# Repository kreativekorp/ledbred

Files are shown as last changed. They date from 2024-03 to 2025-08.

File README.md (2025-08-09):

# ledbred
Led·Bred

## Bill of Materials

* 1x [Arduino Mega 2560 R3](https://store.arduino.cc/products/arduino-mega-2560-rev3) or compatible clone
* 1x [Screw Terminal Shield](https://www.adafruit.com/product/196)
* 1x [MicroSD Shield](https://www.adafruit.com/product/1141)
* 3x [32x8 NeoPixel RGB LED Matrix](https://www.adafruit.com/product/2294) (no longer stocked by Adafruit but clones can be found easily)
* 1x [Breadboard-Friendly NeoPixel RGB LED](https://www.adafruit.com/product/1312)
* 1x [Rotary Encoder with Pushbutton](https://www.adafruit.com/product/377)
* 1x [Monochrome 128x32 SPI OLED Display](https://www.adafruit.com/product/661)
* 1x [HB15CKW01-5F-FB Illuminated Pushbutton](https://www.digikey.com/en/products/detail/nkk-switches/HB15CKW01-5F-FB/1056630)
* 1x [TEPT4400 Photodiode](https://www.digikey.com/en/products/detail/vishay-semiconductor-opto-division/TEPT4400/1681191)
* 1x [Lamping Tool](https://www.digikey.com/en/products/detail/nkk-switches/AT111/1050064) (highly recommended)
* 1x [1MΩ Through-Hole Resistor](https://www.digikey.com/en/products/detail/stackpole-electronics-inc/CF14JT1M00/1741316)

## Construction Diagram

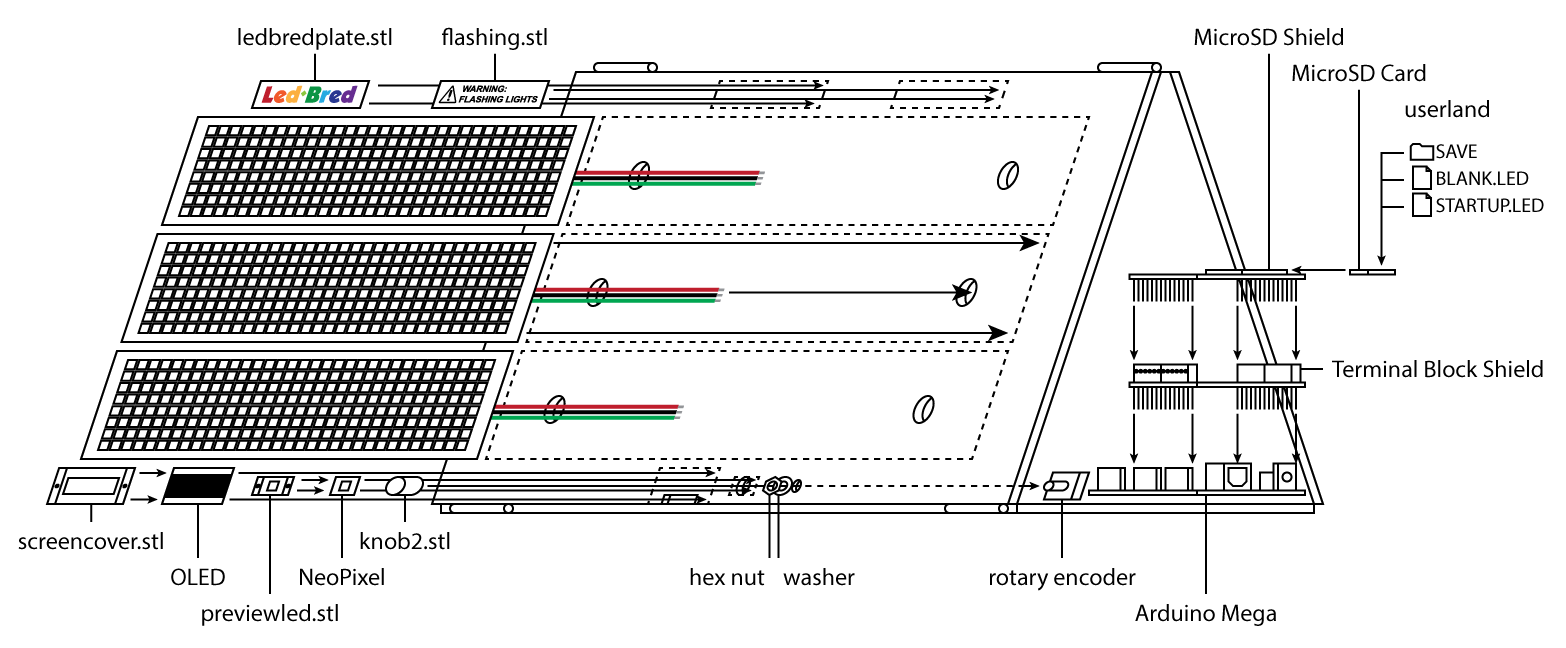
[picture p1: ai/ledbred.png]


## Constructing the pen

1. Use the lamping tool to replace the LED in the illuminated pushbutton with the TEPT4400 photodiode.
2. Blacken the side of the illuminated pushbutton's cap with a Sharpie. (This keeps out ambient light to improve detection.)
3. Install the illuminated pushbutton in the light pen top cap (`pencap1.stl`).
4. Feed the light pen cable through the light pen bottom cap (`pencap2.stl`).
5. Feed the light pen cable through the light pen barrel (`penbarrel.stl`).
6. Solder the wires of the light pen cable to the pins of the illuminated pushbutton.
7. Push the end caps into the barrel.

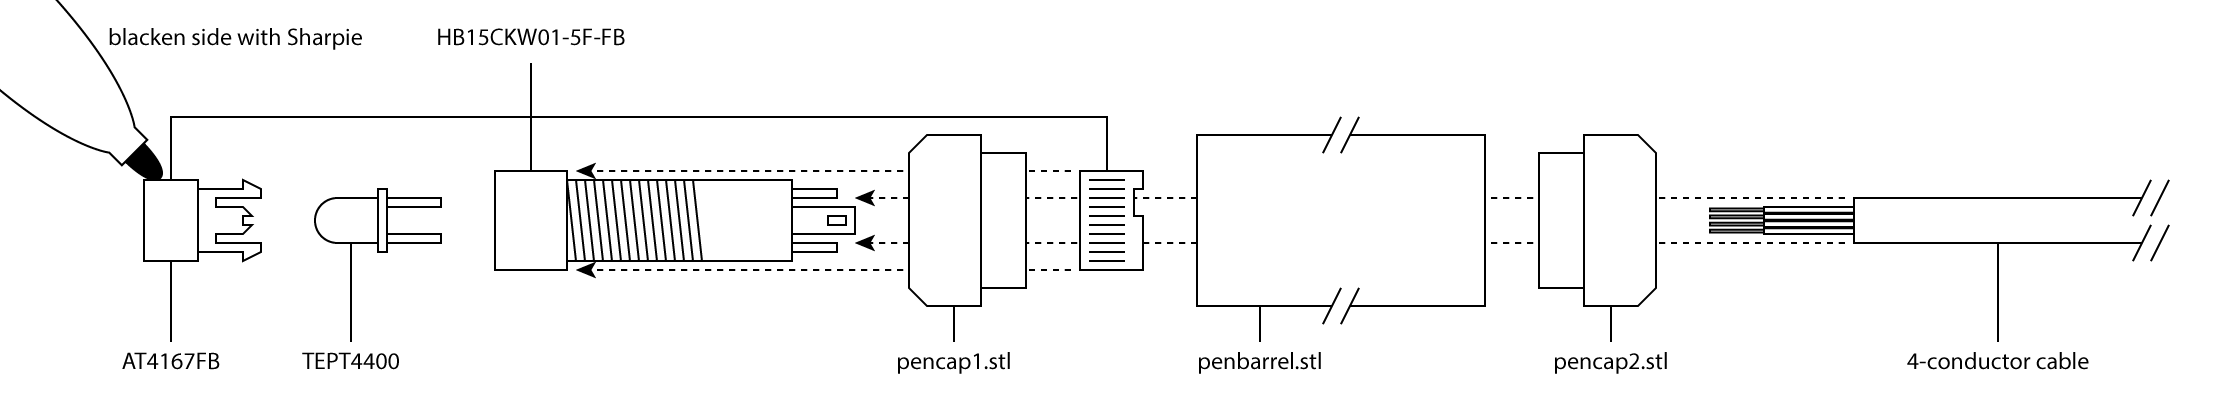
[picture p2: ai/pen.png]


## Wiring Diagram

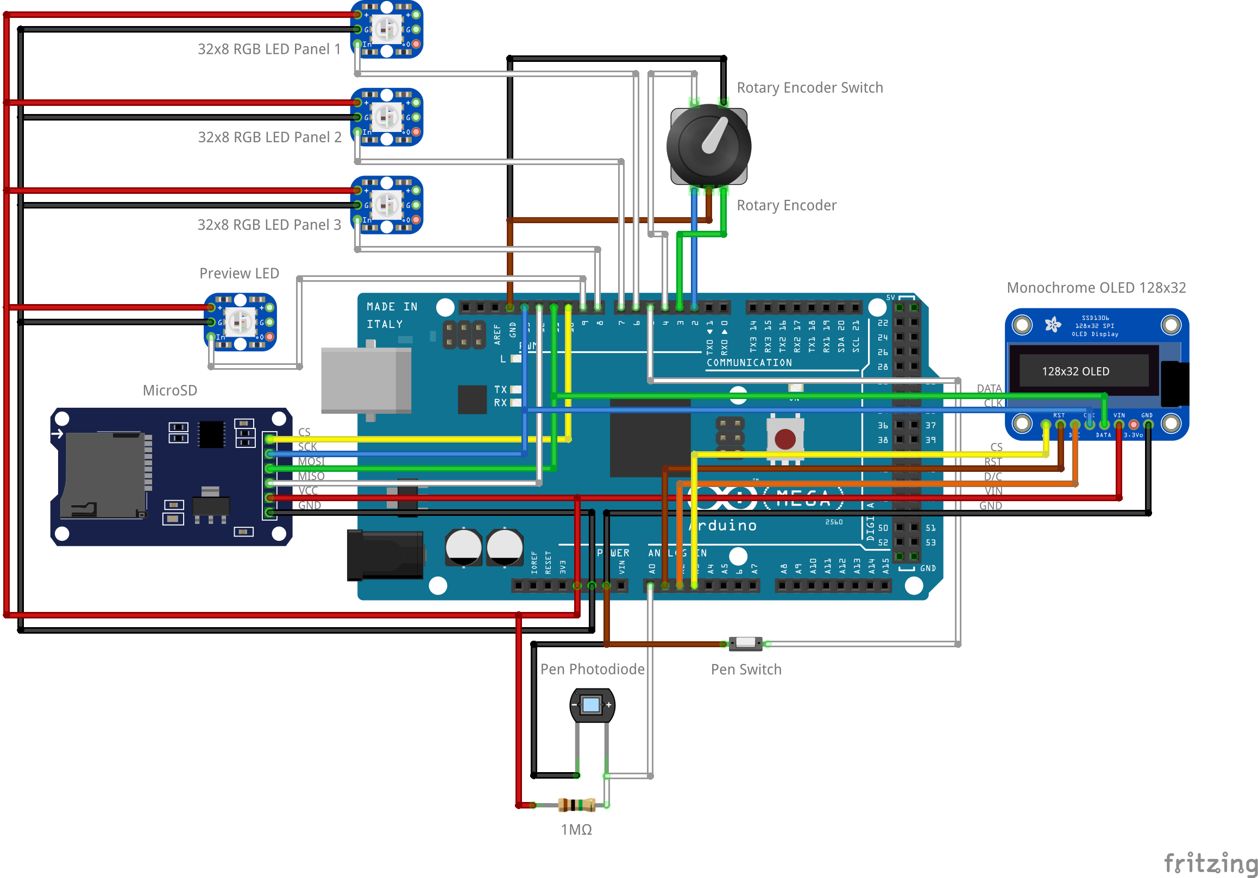
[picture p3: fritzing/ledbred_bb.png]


## Wiring Connections

* Rotary encoder left pin to Arduino D2
* Rotary encoder center pin to GND
* Rotary encoder right pin to Arduino D3
* Rotary encoder switch pin 1 to Arduino D4
* Rotary encoder switch pin 2 to GND
* Illuminated pushbutton switch pin 1 to Arduino D5
* Illuminated pushbutton switch pin 2 to GND
* Top RGB LED matrix DATA IN to Arduino D6
* Center RGB LED matrix DATA IN to Arduino D7
* Bottom RGB LED matrix DATA IN to Arduino D8
* Individual RGB LED DATA IN to Arduino D9
* OLED DATA/MOSI to Arduino D11
* OLED CLK/SCK to Arduino D13
* OLED CS to Arduino A3
* OLED D/C to Arduino A2
* OLED RST to Arduino A1
* Illuminated pushbutton LED anode to Arduino A0
* Illuminated pushbutton LED anode to 1MΩ resistor
* 1MΩ resistor to VCC
* Illuminated pushbutton LED cathode to GND

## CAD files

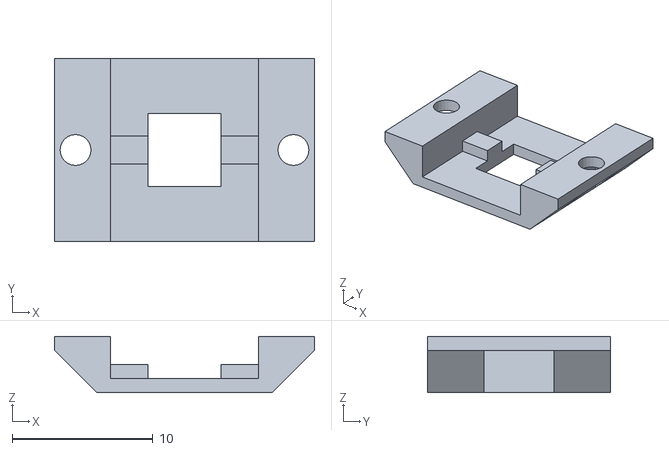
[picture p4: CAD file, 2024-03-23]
stl/previewled.stl
18.5 x 13.0 x 4.00

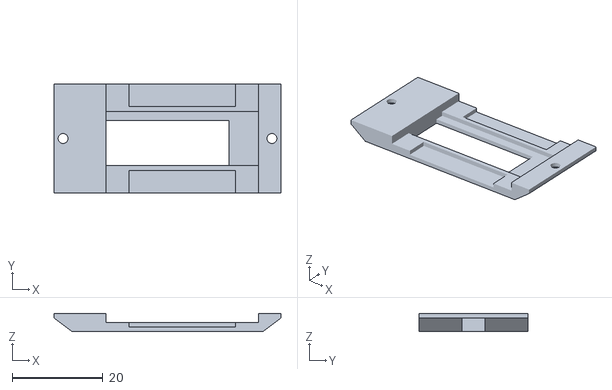
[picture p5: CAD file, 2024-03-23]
stl/screencover.stl
50.0 x 24.0 x 4.00

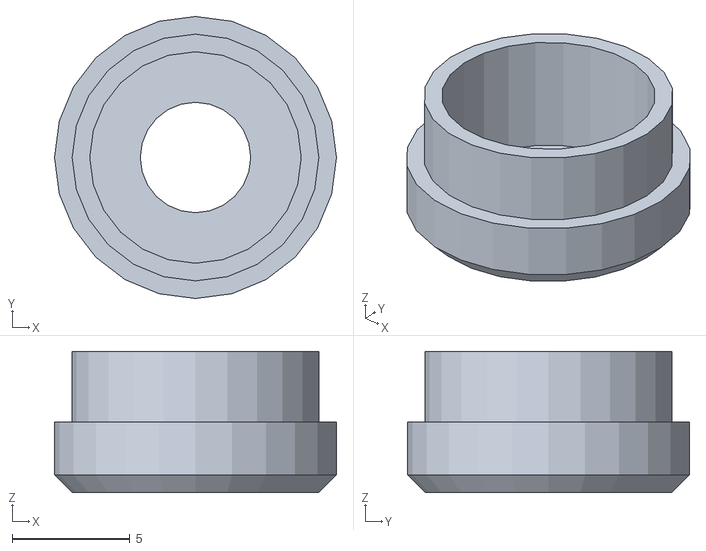
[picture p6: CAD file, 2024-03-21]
stl/pencap2.stl
12.0 x 12.0 x 6.00

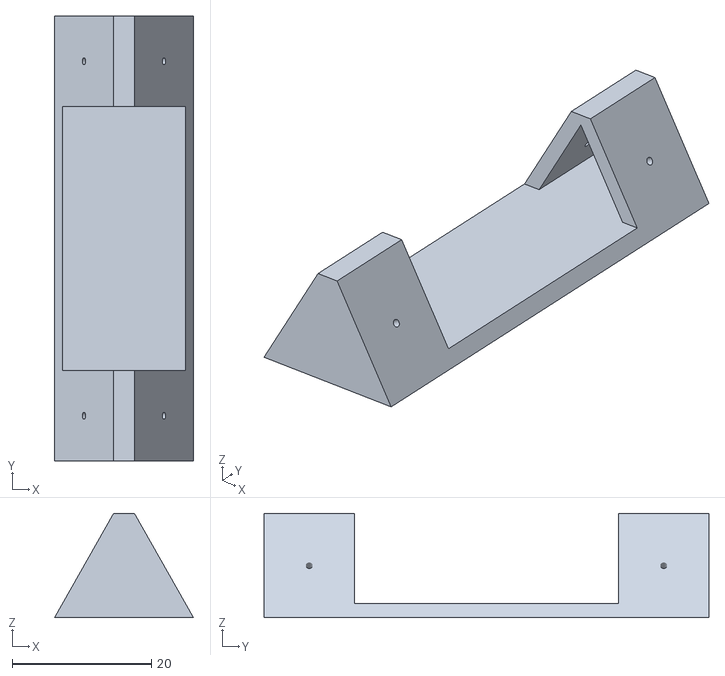
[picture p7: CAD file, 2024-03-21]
stl/triangle.stl
20.0 x 64.0 x 15.0

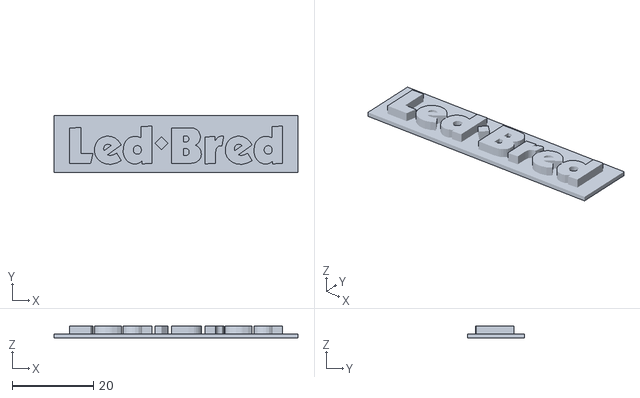
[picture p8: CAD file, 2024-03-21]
stl/ledbredplate.stl
60.0 x 14.0 x 3.00

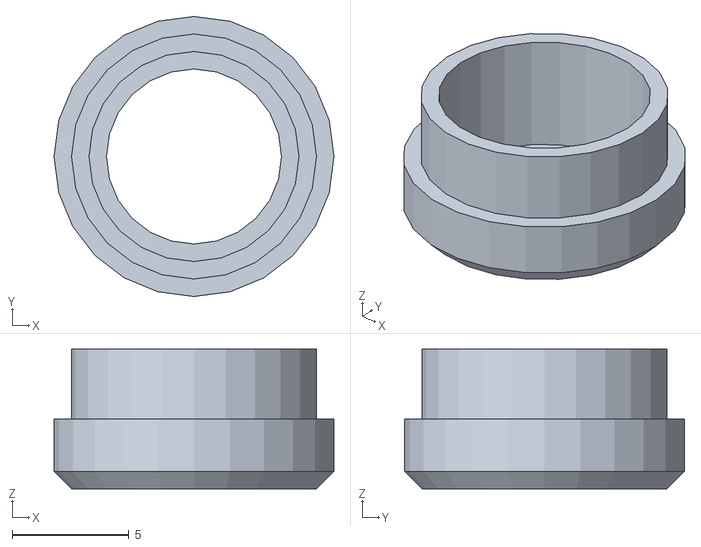
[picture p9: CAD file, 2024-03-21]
stl/pencap1.stl
12.0 x 12.0 x 6.00

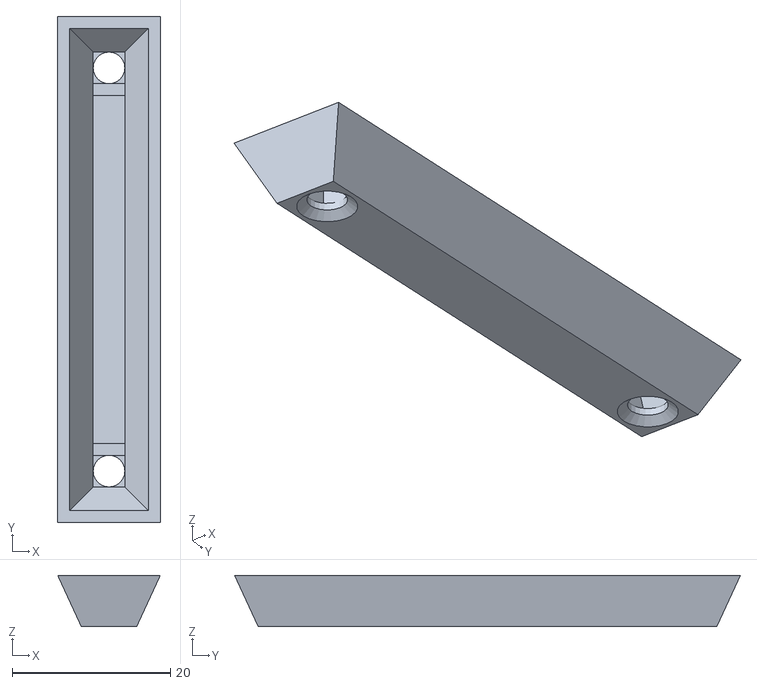
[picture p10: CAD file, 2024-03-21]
stl/ledfoot.stl
13.0 x 64.0 x 6.50

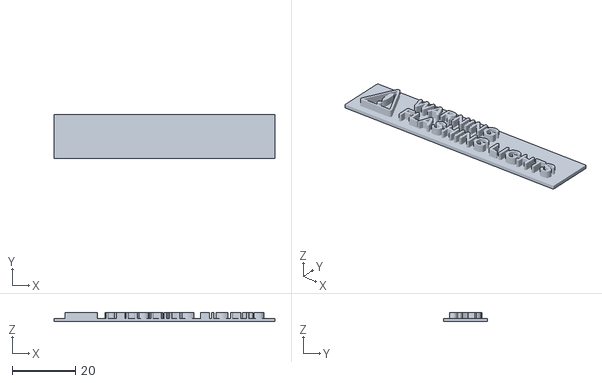
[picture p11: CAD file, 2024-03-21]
stl/flashing.stl
70.0 x 14.0 x 3.00

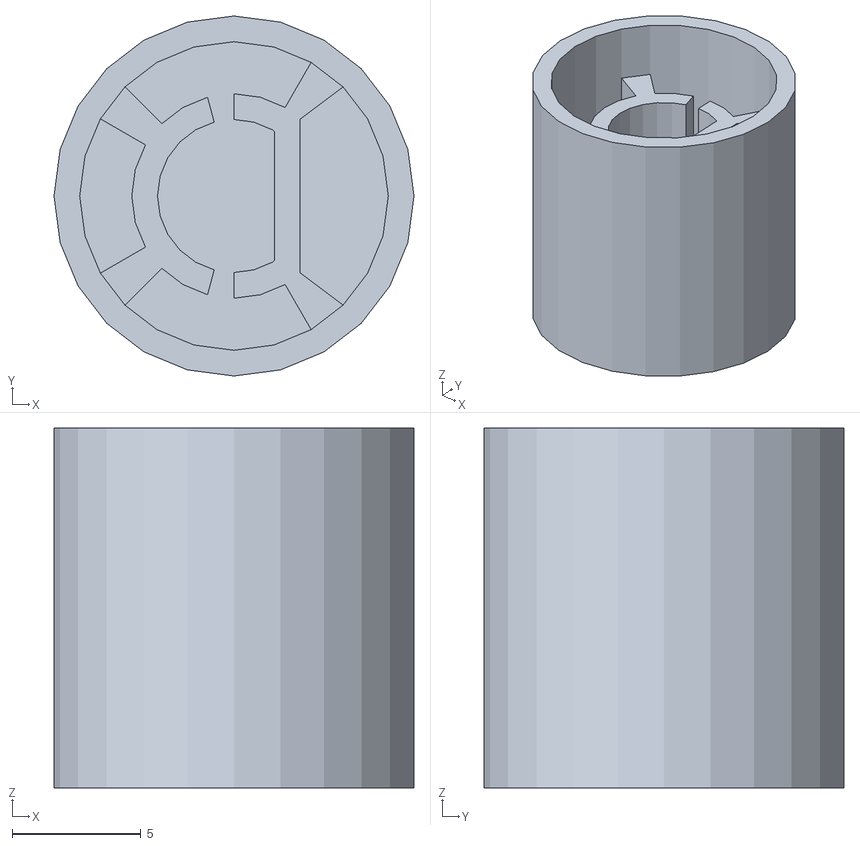
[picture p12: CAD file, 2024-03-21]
stl/knob2.stl
14.0 x 14.0 x 14.0

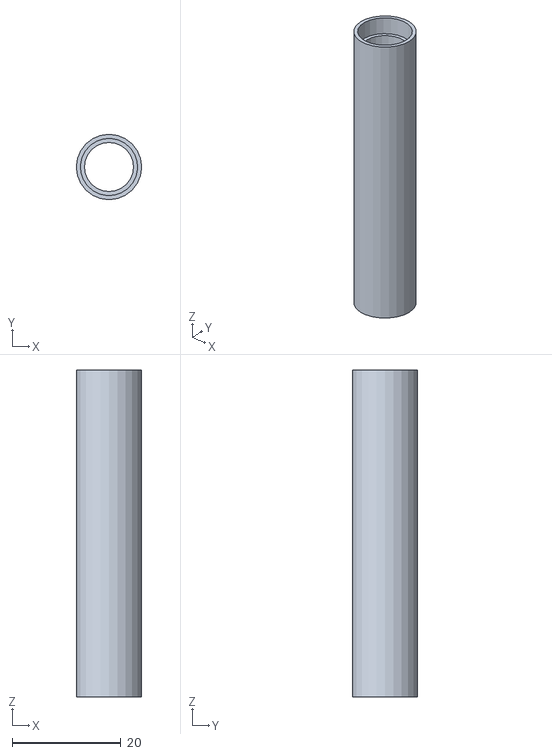
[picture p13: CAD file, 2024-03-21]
stl/penbarrel.stl
12.0 x 12.0 x 60.0

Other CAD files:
sketchup/flashing.skp
sketchup/knob2.skp
sketchup/ledbredplate.skp
sketchup/ledfoot.skp
sketchup/penbarrel.skp
sketchup/pencap1.skp
sketchup/pencap2.skp
sketchup/previewled.skp
sketchup/screencover.skp
sketchup/triangle.skp

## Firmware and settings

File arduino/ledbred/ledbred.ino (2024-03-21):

#include <Adafruit_GFX.h>
#include <Adafruit_SSD1306.h>
#include <Adafruit_NeoPixel.h>
#include <SD.h>
#include <SPI.h>
#include "digitalWriteFast.h"
#include "config.h"
#include "canvas.h"
#include "display.h"
#include "rotary.h"
#include "pen.h"

int sdok = 0;
int currentTask = 0;

void setup() {
  rotaryBegin();
  if (rotaryReadSwitch()) {
    pinMode(13, OUTPUT);
    for (;;) {
      digitalWrite(13, HIGH);
      delay(1000);
      digitalWrite(13, LOW);
      delay(1000);
    }
  }
  penBegin();
  canvasBegin();
  if (penReadSwitch()) {
    int a = 0;
    canvasDebug(a);
    for (;;) {
      int r = rotaryReadDirection();
      if (r) {
        a += r;
        canvasDebug(a);
      }
    }
  }
  displayBegin();
  sdok = SD.begin(SD_CS);
  if (sdok) {
    File sf = SD.open("STARTUP.LED", FILE_READ);
    if (sf) {
      canvasReadPreview(sf);
      sf.close();
      delay(2000);
    }
    sf = SD.open("BLANK.LED", FILE_READ);
    if (sf) {
      canvasRead(sf);
      sf.close();
    } else {
      canvasClear();
    }
  } else {
    displayMessage(23, "No SD card.");
    delay(2000);
  }
  currentTask = 0;
  colorTask();
}

void colorTask() {
  displayColorSelect(canvasGetColor());
  while (!rotaryReadSwitch()) {
    if (penReadSwitch()) {
      canvasPenDetect();
      penDebounce();
    }
    int r = rotaryReadDirection();
    if (r) {
      canvasChangeColor(r);
      displayColorSelect(canvasGetColor());
    }
  }
  rotaryDebounce();
}

void brightnessTask() {
  displayLevelSelect(canvasGetLevel());
  while (!rotaryReadSwitch()) {
    if (penReadSwitch()) {
      canvasPenDetect();
      penDebounce();
    }
    int r = rotaryReadDirection();
    if (r) {
      canvasChangeLevel(r);
      displayLevelSelect(canvasGetLevel());
    }
  }
  rotaryDebounce();
}

void messageTask(int icon, const char * str) {
  displayMessage(icon, str);
  while (!rotaryReadSwitch()) {
    if (penReadSwitch()) {
      canvasPenDetect();
      penDebounce();
    }
  }
  rotaryDebounce();
}

int confirmTask(const char * str, int i) {
  displayConfirmation(str, i);
  while (!rotaryReadSwitch()) {
    if (penReadSwitch()) {
      canvasPenDetect();
      penDebounce();
    }
    int r = rotaryReadDirection();
    if (r) {
      i = (r < 0);
      displayConfirmation(str, i);
    }
  }
  rotaryDebounce();
  return i;
}

int menuTask(int n, const int * icons, const char ** items, int i) {
  displayMenuSelect(n, icons, items, i);
  while (!rotaryReadSwitch()) {
    if (penReadSwitch()) {
      canvasPenDetect();
      penDebounce();
    }
    int r = rotaryReadDirection();
    if (r) {
      if ((i = (i + r) % n) < 0) i += n;
      displayMenuSelect(n, icons, items, i);
    }
  }
  rotaryDebounce();
  return i;
}

int isLedFile(File & entry) {
  if (!entry) return 0;
  if (entry.isDirectory()) return 0;
  int n = strlen(entry.name()) - 4;
  if (n < 0) return 0;
  if (entry.name()[n] != '.') return 0;
  if (entry.name()[n+1] != 'L') return 0;
  if (entry.name()[n+2] != 'E') return 0;
  if (entry.name()[n+3] != 'D') return 0;
  return 1;
}

File directoryTask(File & dir) {
  int n = 0;
  dir.rewindDirectory();
  File entry = dir.openNextFile();
  while (entry) {
    if (isLedFile(entry)) n++;
    entry.close();
    entry = dir.openNextFile();
  }
  int i = n;
  displayFileSelect(i, n, "Exit");
  while (!rotaryReadSwitch()) {
    int r = rotaryReadDirection();
    if (r) {
      if ((i = (i + r) % (n+1)) < 0) i += (n+1);
      if (entry) entry.close();
      r = 0;
      dir.rewindDirectory();
      entry = dir.openNextFile();
      while (entry) {
        if (isLedFile(entry)) {
          if (r == i) break;
          r++;
        }
        entry.close();
        entry = dir.openNextFile();
      }
      if (entry) {
        displayFileSelect(i, n, entry.name());
        canvasReadPreview(entry);
        entry.seek(0);
      } else {
        displayFileSelect(i, n, "Exit");
        canvasUpdate();
      }
    }
  }
  rotaryDebounce();
  return entry;
}

void clearTask() {
  if (confirmTask("Clear picture?", 0)) {
    if (sdok) {
      File sf = SD.open("BLANK.LED");
      if (sf) {
        canvasRead(sf);
        sf.close();
        return;
      }
    }
    canvasClear();
  }
}

void loadTask() {
  if (sdok) {
    File dir = SD.open("/SAVE/");
    if (dir) {
      if (dir.isDirectory()) {
        File entry = directoryTask(dir);
        if (entry) {
          canvasRead(entry);
          entry.close();
        }
        return;
      }
      dir.close();
    }
    dir = SD.open("/");
    if (dir) {
      if (dir.isDirectory()) {
        File entry = directoryTask(dir);
        if (entry) {
          canvasRead(entry);
          entry.close();
        }
        return;
      }
      dir.close();
    }
    messageTask(23, "I/O error.");
  } else {
    messageTask(23, "No SD card.");
  }
}

static const char save_path[] PROGMEM = "SAVE/SAVE0000.LED";
static const char save_msg[] PROGMEM = "Saved as";

void saveTask() {
  if (sdok) {
    if (confirmTask("Save picture?", 1)) {
      char path[24];
      strcpy_P(path, save_path);
      while (SD.exists(path)) {
        if ((++path[12]) <= '9') continue;
        path[12] = '0';
        if ((++path[11]) <= '9') continue;
        path[11] = '0';
        if ((++path[10]) <= '9') continue;
        path[10] = '0';
        if ((++path[9]) <= '9') continue;
        path[9] = '0';
      }
      File file = SD.open(path, FILE_WRITE);
      if (file) {
        canvasWrite(file);
        file.close();
        strcpy_P(path, save_msg);
        path[8] = ' ';
        path[14] = 0;
        messageTask(20, path);
        return;
      }
      while (SD.exists(&path[5])) {
        if ((++path[12]) <= '9') continue;
        path[12] = '0';
        if ((++path[11]) <= '9') continue;
        path[11] = '0';
        if ((++path[10]) <= '9') continue;
        path[10] = '0';
        if ((++path[9]) <= '9') continue;
        path[9] = '0';
      }
      file = SD.open(&path[5], FILE_WRITE);
      if (file) {
        canvasWrite(file);
        file.close();
        strcpy_P(path, save_msg);
        path[8] = ' ';
        path[14] = 0;
        messageTask(20, path);
        return;
      }
      messageTask(23, "I/O error.");
    }
  } else {
    messageTask(23, "No SD card.");
  }
}

#define MENU_ITEM_COUNT 5
static const int menu_icons[] PROGMEM = { 24, 17, 25, 21, 22 };
static const char menu_item_0[] PROGMEM = "Select Color";
static const char menu_item_1[] PROGMEM = "Set Brightness";
static const char menu_item_2[] PROGMEM = "Clear Picture";
static const char menu_item_3[] PROGMEM = "Load Picture";
static const char menu_item_4[] PROGMEM = "Save Picture";
static const char * const menu_items[] PROGMEM = {
  menu_item_0, menu_item_1, menu_item_2, menu_item_3, menu_item_4,
};

void loop() {
  currentTask = menuTask(MENU_ITEM_COUNT, menu_icons, menu_items, currentTask);
  switch (currentTask) {
    case 0: colorTask(); return;
    case 1: brightnessTask(); return;
    case 2: clearTask(); break;
    case 3: loadTask(); break;
    case 4: saveTask(); break;
  }
  currentTask = 0;
  colorTask();
}

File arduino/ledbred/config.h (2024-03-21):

#ifndef CONFIG_H
#define CONFIG_H

#define ROTARY_CK_PIN   2
#define ROTARY_DT_PIN   3
#define ROTARY_SW_PIN   4
#define ROTARY_DEBOUNCE 50

#define PEN_PIN         5
#define PEN_DEBOUNCE    50

#define CANVAS_1_NUM    256
#define CANVAS_1_PIN    6
#define CANVAS_1_SET    (NEO_GRB + NEO_KHZ800)

#define CANVAS_2_NUM    256
#define CANVAS_2_PIN    7
#define CANVAS_2_SET    (NEO_GRB + NEO_KHZ800)

#define CANVAS_3_NUM    256
#define CANVAS_3_PIN    8
#define CANVAS_3_SET    (NEO_GRB + NEO_KHZ800)

#define PREVIEW_NUM     1
#define PREVIEW_PIN     9
#define PREVIEW_SET     (NEO_GRB + NEO_KHZ800)

#define SENSE_PIN       A0
#define SENSE_LEVELS    0x01010101
#define SENSE_DURATION  3
#define SENSE_THRESHOLD <128

#define BUFFER_PIXELS   64

#define SD_CS           10
#define SD_MOSI         11
#define SD_MISO         12
#define SD_SCK          13

#define SCREEN_WIDTH    128
#define SCREEN_HEIGHT   32
#define OLED_MOSI       11
#define OLED_CLK        13
#define OLED_RESET      A1
#define OLED_DC         A2
#define OLED_CS         A3

#define RTC_SDA         A4
#define RTC_SCL         A5

#endif

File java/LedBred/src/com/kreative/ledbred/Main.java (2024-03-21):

package com.kreative.ledbred;

import java.awt.FileDialog;
import java.awt.Frame;
import java.awt.Graphics2D;
import java.awt.Rectangle;
import java.awt.Toolkit;
import java.awt.image.BufferedImage;
import java.io.File;
import java.io.FileInputStream;
import java.io.FileOutputStream;
import java.io.IOException;
import java.lang.reflect.Field;
import java.lang.reflect.Method;
import java.util.Scanner;
import javax.imageio.ImageIO;
import javax.swing.JOptionPane;
import javax.swing.UIManager;

public class Main {
	public static void main(String[] args) {
		try { System.setProperty("com.apple.mrj.application.apple.menu.about.name", "Led·Bred"); } catch (Exception e) {}
		try { System.setProperty("apple.laf.useScreenMenuBar", "true"); } catch (Exception e) {}
		try { UIManager.setLookAndFeel(UIManager.getSystemLookAndFeelClassName()); } catch (Exception e) {}
		
		try {
			Method getModule = Class.class.getMethod("getModule");
			Object javaDesktop = getModule.invoke(Toolkit.getDefaultToolkit().getClass());
			Object allUnnamed = getModule.invoke(Main.class);
			Class<?> module = Class.forName("java.lang.Module");
			Method addOpens = module.getMethod("addOpens", String.class, module);
			addOpens.invoke(javaDesktop, "sun.awt.X11", allUnnamed);
		} catch (Exception e) {}
		
		try {
			Toolkit tk = Toolkit.getDefaultToolkit();
			Field aacn = tk.getClass().getDeclaredField("awtAppClassName");
			aacn.setAccessible(true);
			aacn.set(tk, "Led·Bred");
		} catch (Exception e) {}
		
		File save = LedUtility.saveDirectory();
		lastOpenDirectory = save.getAbsolutePath();
		lastSaveDirectory = save.getAbsolutePath();
		
		LedCanvas canvas = new LedCanvas();
		boolean autoHint = true;
		boolean configHint = false;
		boolean pictureHint = false;
		boolean parseOptions = true;
		for (String arg : args) {
			if (parseOptions && arg.startsWith("-")) {
				if (arg.equals("--")) {
					parseOptions = false;
				} else if (arg.equals("-a")) {
					autoHint = true;
					configHint = false;
					pictureHint = false;
				} else if (arg.equals("-c")) {
					autoHint = false;
					configHint = true;
					pictureHint = false;
				} else if (arg.equals("-p")) {
					autoHint = false;
					configHint = false;
					pictureHint = true;
				} else {
					System.err.println("Unknown option: " + arg);
				}
			} else {
				File file = new File(arg);
				String nn = file.getName().toLowerCase();
				if (configHint || (autoHint && nn.endsWith(".ini"))) {
					try {
						Scanner scan = new Scanner(file);
						canvas.clear();
						canvas.add(scan);
						scan.close();
					} catch (IOException e) {
						System.err.println("Cannot load " + file + ": " + e);
					}
					autoHint = true;
					configHint = false;
					pictureHint = false;
					continue;
				}
				if (pictureHint || (autoHint && nn.endsWith(".led"))) {
					checkConfig(canvas);
					try {
						FileInputStream in = new FileInputStream(file);
						canvas.read(in);
						in.close();
					} catch (IOException e) {
						System.err.println("Cannot load " + file + ": " + e);
					}
					autoHint = true;
					configHint = false;
					pictureHint = false;
					continue;
				}
				System.err.println("Unknown file type: " + file);
			}
		}
		
		checkConfig(canvas);
		new LedBredFrame(canvas).setVisible(true);
	}
	
	private static void checkConfig(LedCanvas canvas) {
		if (canvas.isEmpty()) {
			try {
				File file = LedUtility.configFile();
				Scanner scan = new Scanner(file);
				canvas.add(scan);
				scan.close();
			} catch (IOException e) {
				System.err.println("Cannot load LEDBRED.INI: " + e);
			}
			if (canvas.isEmpty()) {
				canvas.add(new LedPanel(0, 0, 8, 8, WindingOrder.LTR_TTB));
			}
		}
	}
	
	private static String lastOpenDirectory = null;
	public static File getOpenFile() {
		Frame frame = new Frame();
		FileDialog fd = new FileDialog(frame, "Open", FileDialog.LOAD);
		if (lastOpenDirectory != null) fd.setDirectory(lastOpenDirectory);
		fd.setVisible(true);
		String ds = fd.getDirectory(), fs = fd.getFile();
		fd.dispose();
		frame.dispose();
		if (ds == null || fs == null) return null;
		return new File((lastOpenDirectory = ds), fs);
	}
	
	public static boolean openPicture(LedCanvas canvas, File file) {
		if (file == null) {
			file = getOpenFile();
			if (file == null) return false;
		}
		try {
			FileInputStream in = new FileInputStream(file);
			canvas.read(in);
			in.close();
			return true;
		} catch (IOException e) {
			JOptionPane.showMessageDialog(
				null, "An error occurred while opening this file.",
				"Open", JOptionPane.ERROR_MESSAGE
			);
			return false;
		}
	}
	
	public static boolean importPicture(LedCanvas canvas, File file) {
		if (file == null) {
			file = getOpenFile();
			if (file == null) return false;
		}
		try {
			BufferedImage rendered = ImageIO.read(file);
			if (rendered == null) return false;
			Rectangle bounds = canvas.getBounds();
			if (bounds == null) return false;
			BufferedImage scaled = new BufferedImage(bounds.width, bounds.height, BufferedImage.TYPE_INT_ARGB);
			Graphics2D g = scaled.createGraphics();
			g.drawImage(rendered, 0, 0, bounds.width, bounds.height, null);
			g.dispose();
			canvas.fromBufferedImage(scaled, 0, 0);
			return true;
		} catch (IOException e) {
			JOptionPane.showMessageDialog(
				null, "An error occurred while opening this file.",
				"Open", JOptionPane.ERROR_MESSAGE
			);
			return false;
		}
	}
	
	private static String lastSaveDirectory = null;
	public static File getSaveFile(String suffix) {
		Frame frame = new Frame();
		FileDialog fd = new FileDialog(frame, "Save", FileDialog.SAVE);
		if (lastSaveDirectory != null) fd.setDirectory(lastSaveDirectory);
		fd.setVisible(true);
		String ds = fd.getDirectory(), fs = fd.getFile();
		fd.dispose();
		frame.dispose();
		if (ds == null || fs == null) return null;
		if (!fs.toLowerCase().endsWith(suffix.toLowerCase())) fs += suffix;
		return new File((lastSaveDirectory = ds), fs);
	}
	
	public static boolean savePicture(LedCanvas canvas, File file) {
		if (file == null) {
			file = getSaveFile(".LED");
			if (file == null) return false;
		}
		try {
			FileOutputStream out = new FileOutputStream(file);
			canvas.write(out);
			out.close();
			return true;
		} catch (IOException e) {
			JOptionPane.showMessageDialog(
				null, "An error occurred while saving this file.",
				"Save", JOptionPane.ERROR_MESSAGE
			);
			return false;
		}
	}
	
	public static boolean exportPicture(LedCanvas canvas, File file) {
		if (file == null) {
			file = getSaveFile(".png");
			if (file == null) return false;
		}
		try {
			BufferedImage image = canvas.toBufferedImage(null, 0, 0);
			if (image == null) return false;
			ImageIO.write(image, "png", file);
			return true;
		} catch (IOException e) {
			JOptionPane.showMessageDialog(
				null, "An error occurred while saving this file.",
				"Save", JOptionPane.ERROR_MESSAGE
			);
			return false;
		}
	}
}

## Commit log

2024-03-21 Initial import
    [flashing.skp, flashing.stl, knob2.skp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]
2024-03-23 More 3D printed parts
    [previewled.skp, previewled.stl, screencover.skp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]
2025-08-08 Wiring diagram
    [ledbred.fzz]
2025-08-09 Correct direction of threads
